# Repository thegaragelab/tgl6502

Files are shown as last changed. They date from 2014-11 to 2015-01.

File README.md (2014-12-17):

# The TGL-6502 Single Board Computer

This project implements 6502 emulator running in 4K of flash on an LPC810
microcontroller. For more information please visit [this site](http://thegaragelab.com/posts/introducing-the-tgl-6502-single-board-computer.html).

The TGL-6502

## Hardware

The hardware is very simple - the CPU itself, an SPI IO expander, two SPI memory
chips and some discrete logic. Full schematics and PCB layouts have been provided
in the *hardware* directory. The current board revision is RevB, all future work
will be using that hardware.

The hardware design is provide in [DesignSpark PCB](http://www.rs-online.com/designspark/electronics/eng/page/designspark-pcb-home-page)
format - this is a free, fully featured schematic capture and PCB layout tool
Additional formats (PDF and gerber files) have been provided in the *hardware/RevB/mfr*
directory if you prefer to use a different tool.

## Firmware

The firmware consists of a [LPCXpresso](http://www.lpcware.com/lpcxpresso) project
but is in the process of migrating to a *makefile* based build system.

## Licensing

The project is being released under the [Creative Commons Attribution-ShareAlike](http://creativecommons.org/licenses/by-sa/4.0/)
license. Some components of the project are sourced from others - their licenses
are included in their source directories.

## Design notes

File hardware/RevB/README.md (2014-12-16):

= TGL-6502 Hardware Revision B

This directory contains the design files for the RevB version of the hardware.
The core processor is still the LPC810 but the IO expander has been replaced
with a [MCP23S08](http://www.microchip.com/wwwproducts/Devices.aspx?product=MCP23S08)
8 bit expander and one of the expansion slots has been removed. The firmware will
be updated to reflect the hardware changes, the original firmware remains available
in the 'RevA' branch of the repository and any applicable changes will be merged
across as needed.

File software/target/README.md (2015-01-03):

18-Dec-2014 ShaneG

This directory contains software for the target device.

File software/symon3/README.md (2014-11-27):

This contains the source and manual for SyMON III - a system monitor for use in
6502 based systems. The original source and documentation can be found here:

        http://mypeoplepc.com/members/spacebacker/SyMon/id12.html

The source implementation uses interrupt driven IO, something the TGL-6502 does
not (yet) support.

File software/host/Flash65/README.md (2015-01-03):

18-Dec-2014 ShaneG

This utility uses a very simple protocol to transfer data to the EEPROM on the
target device.

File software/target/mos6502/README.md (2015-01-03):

18-Dec-2014 ShaneG

This directory contains 6502 specific software (mostly in assembly).

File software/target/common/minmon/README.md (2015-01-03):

20-Dec-2014 ShaneG

This contains source for a minimal monitor program (MinMon). This is designed to
make it relatively easy to manipulate memory and IO on the target device while
remaining portable. It does require a C compiler for the target.

# Memory Layout

MinMon is designed to be placed in the ROM of the target but will copy itself
to a RAM page on initialisation.

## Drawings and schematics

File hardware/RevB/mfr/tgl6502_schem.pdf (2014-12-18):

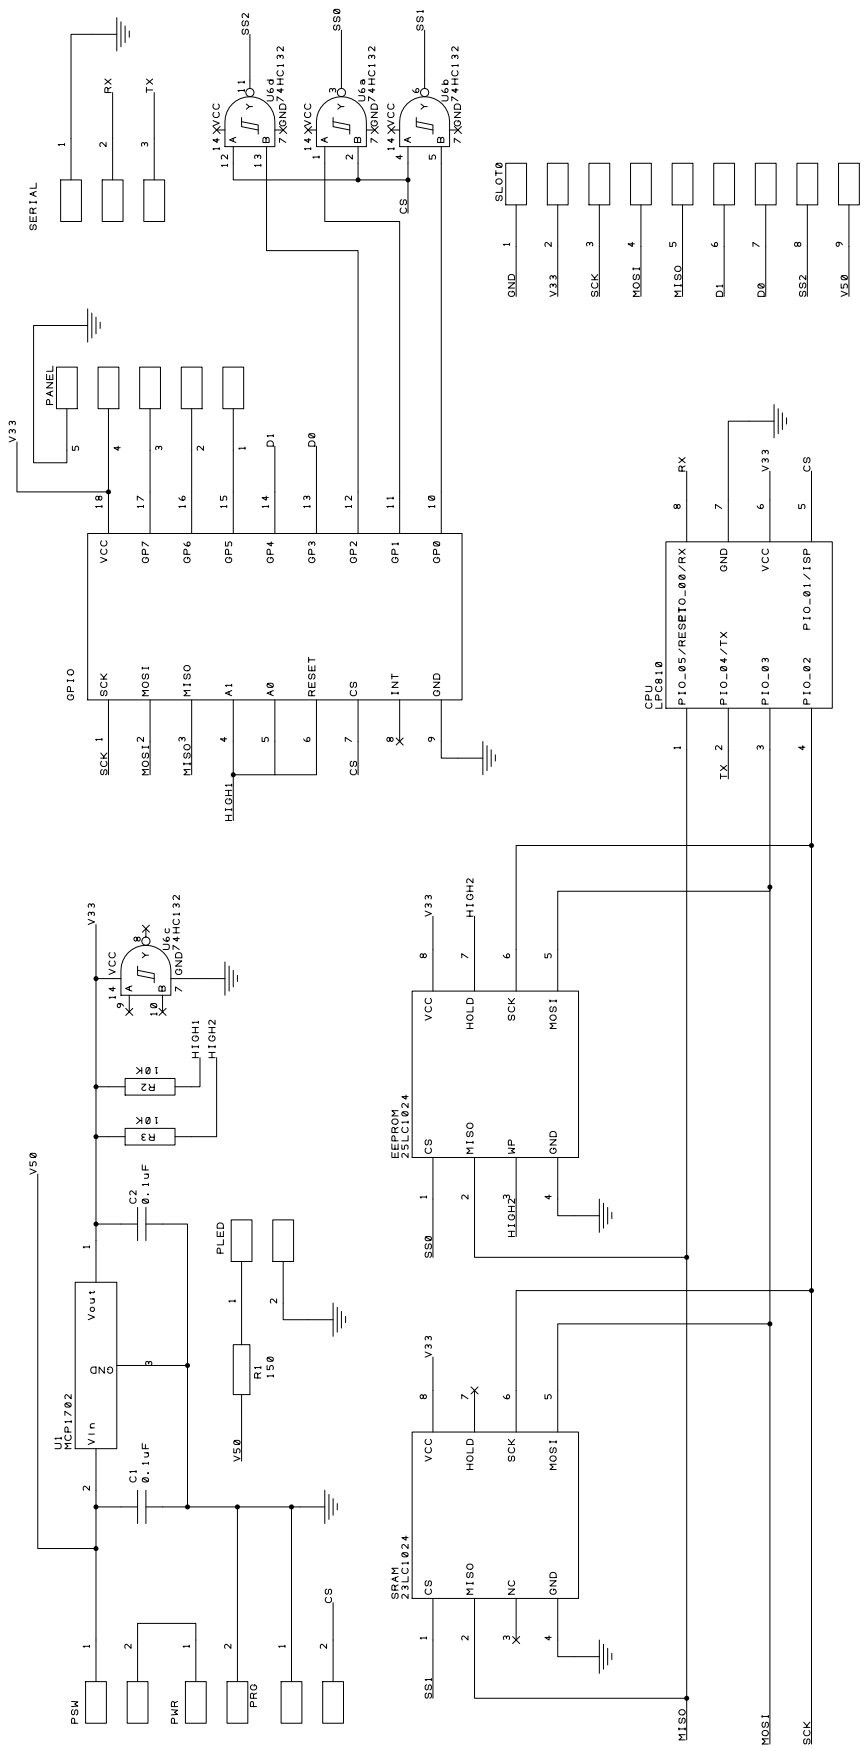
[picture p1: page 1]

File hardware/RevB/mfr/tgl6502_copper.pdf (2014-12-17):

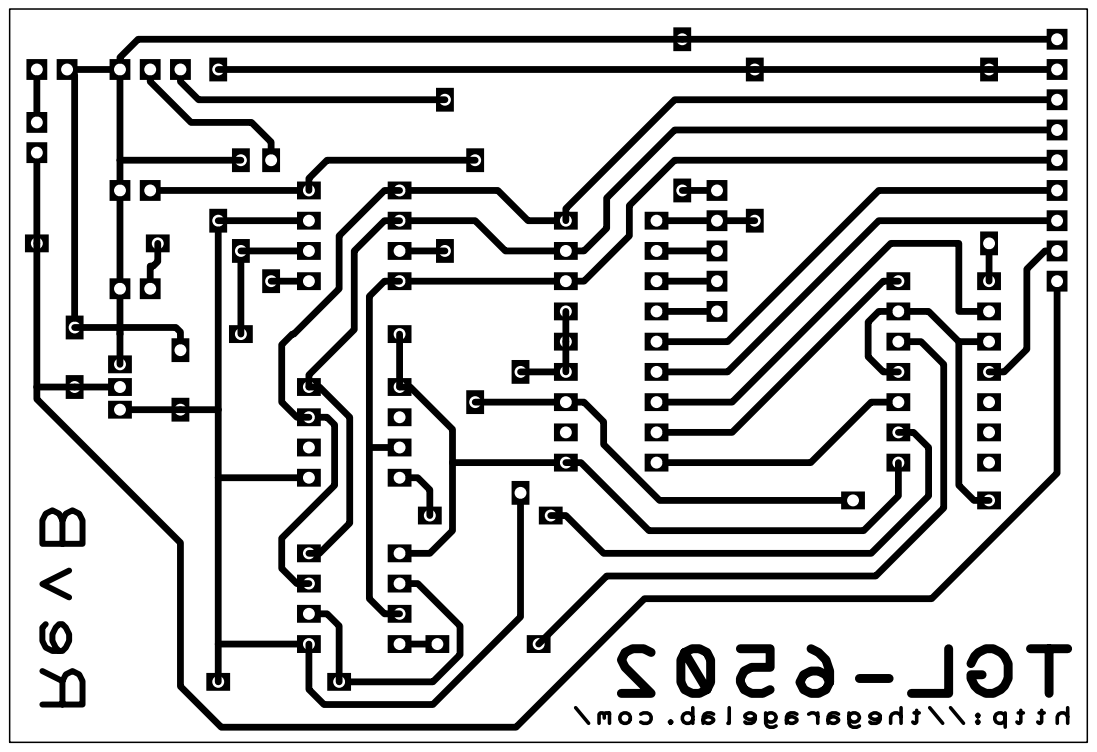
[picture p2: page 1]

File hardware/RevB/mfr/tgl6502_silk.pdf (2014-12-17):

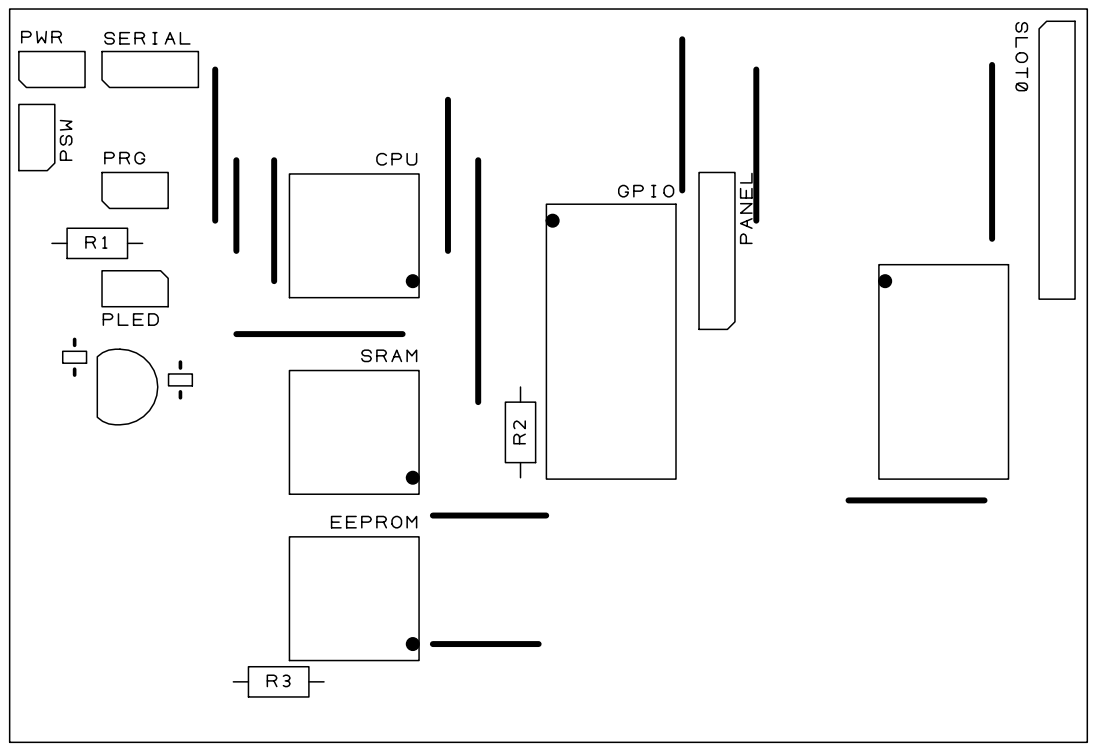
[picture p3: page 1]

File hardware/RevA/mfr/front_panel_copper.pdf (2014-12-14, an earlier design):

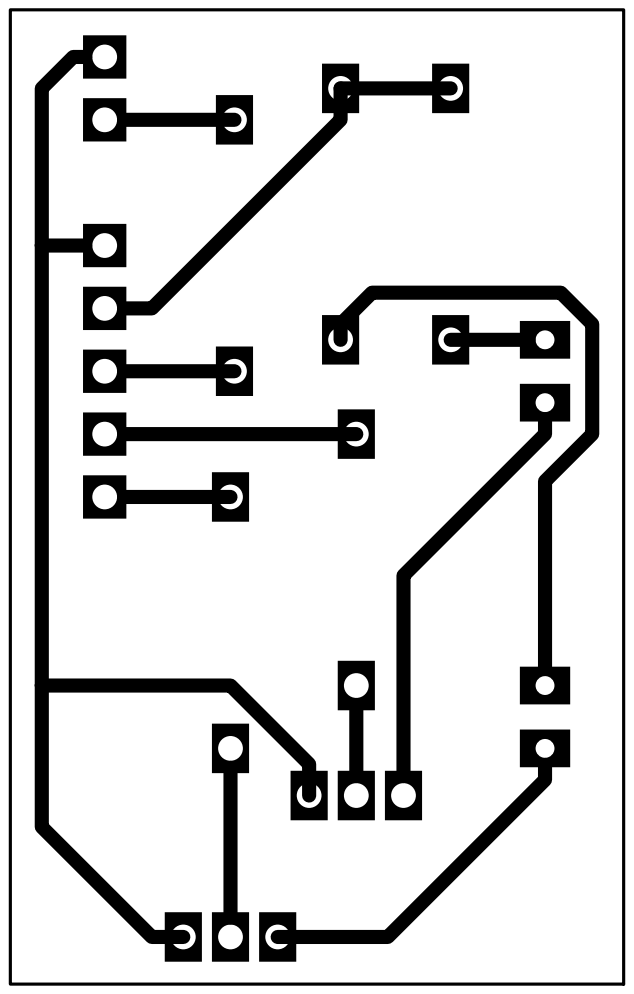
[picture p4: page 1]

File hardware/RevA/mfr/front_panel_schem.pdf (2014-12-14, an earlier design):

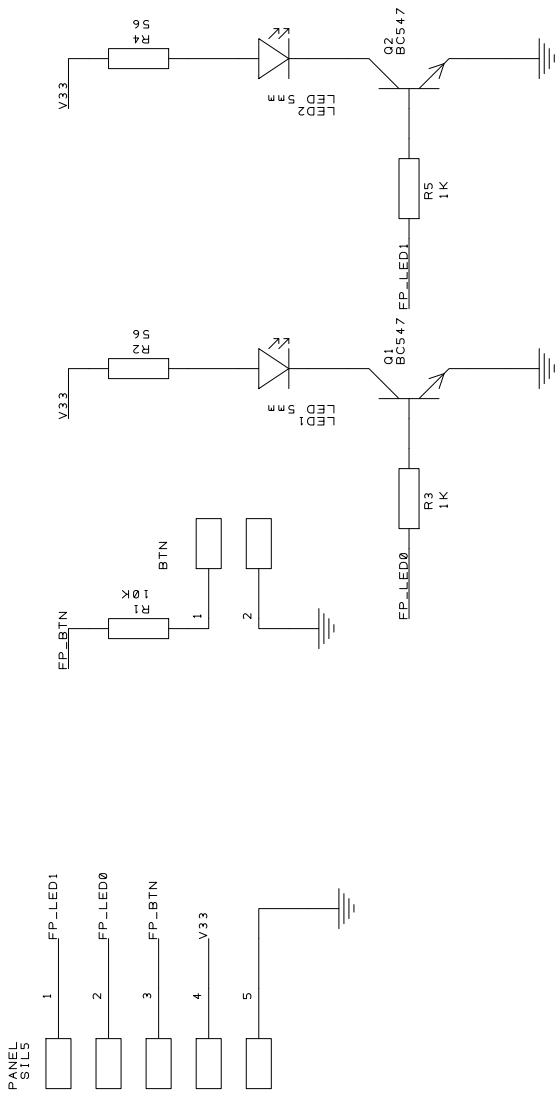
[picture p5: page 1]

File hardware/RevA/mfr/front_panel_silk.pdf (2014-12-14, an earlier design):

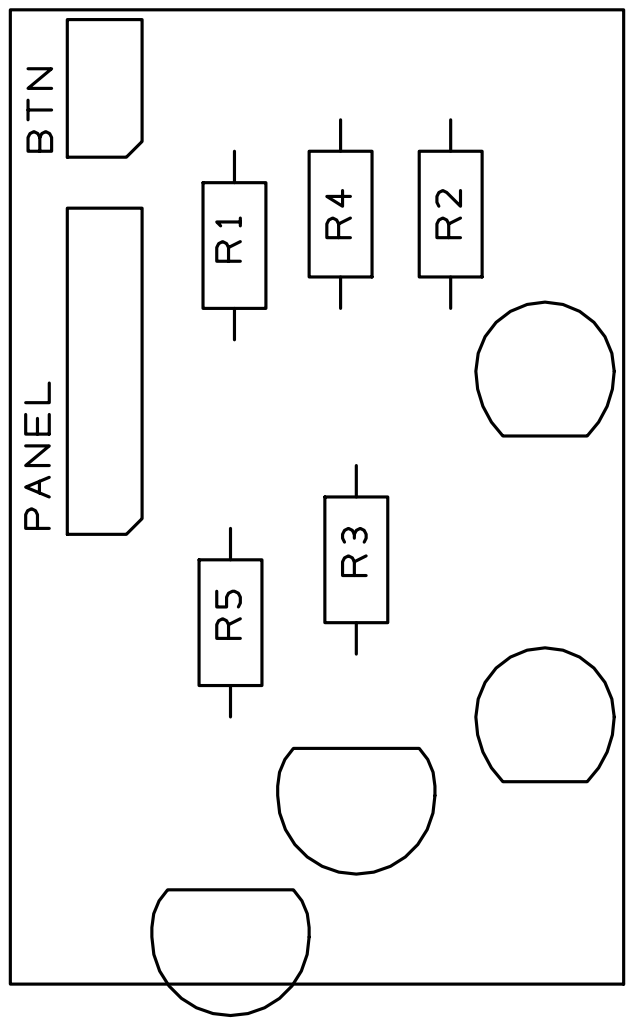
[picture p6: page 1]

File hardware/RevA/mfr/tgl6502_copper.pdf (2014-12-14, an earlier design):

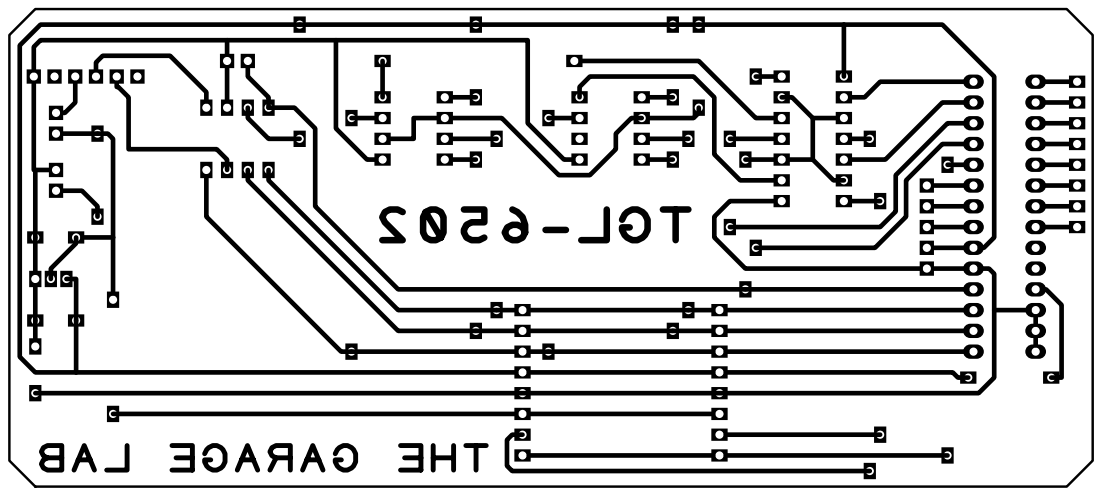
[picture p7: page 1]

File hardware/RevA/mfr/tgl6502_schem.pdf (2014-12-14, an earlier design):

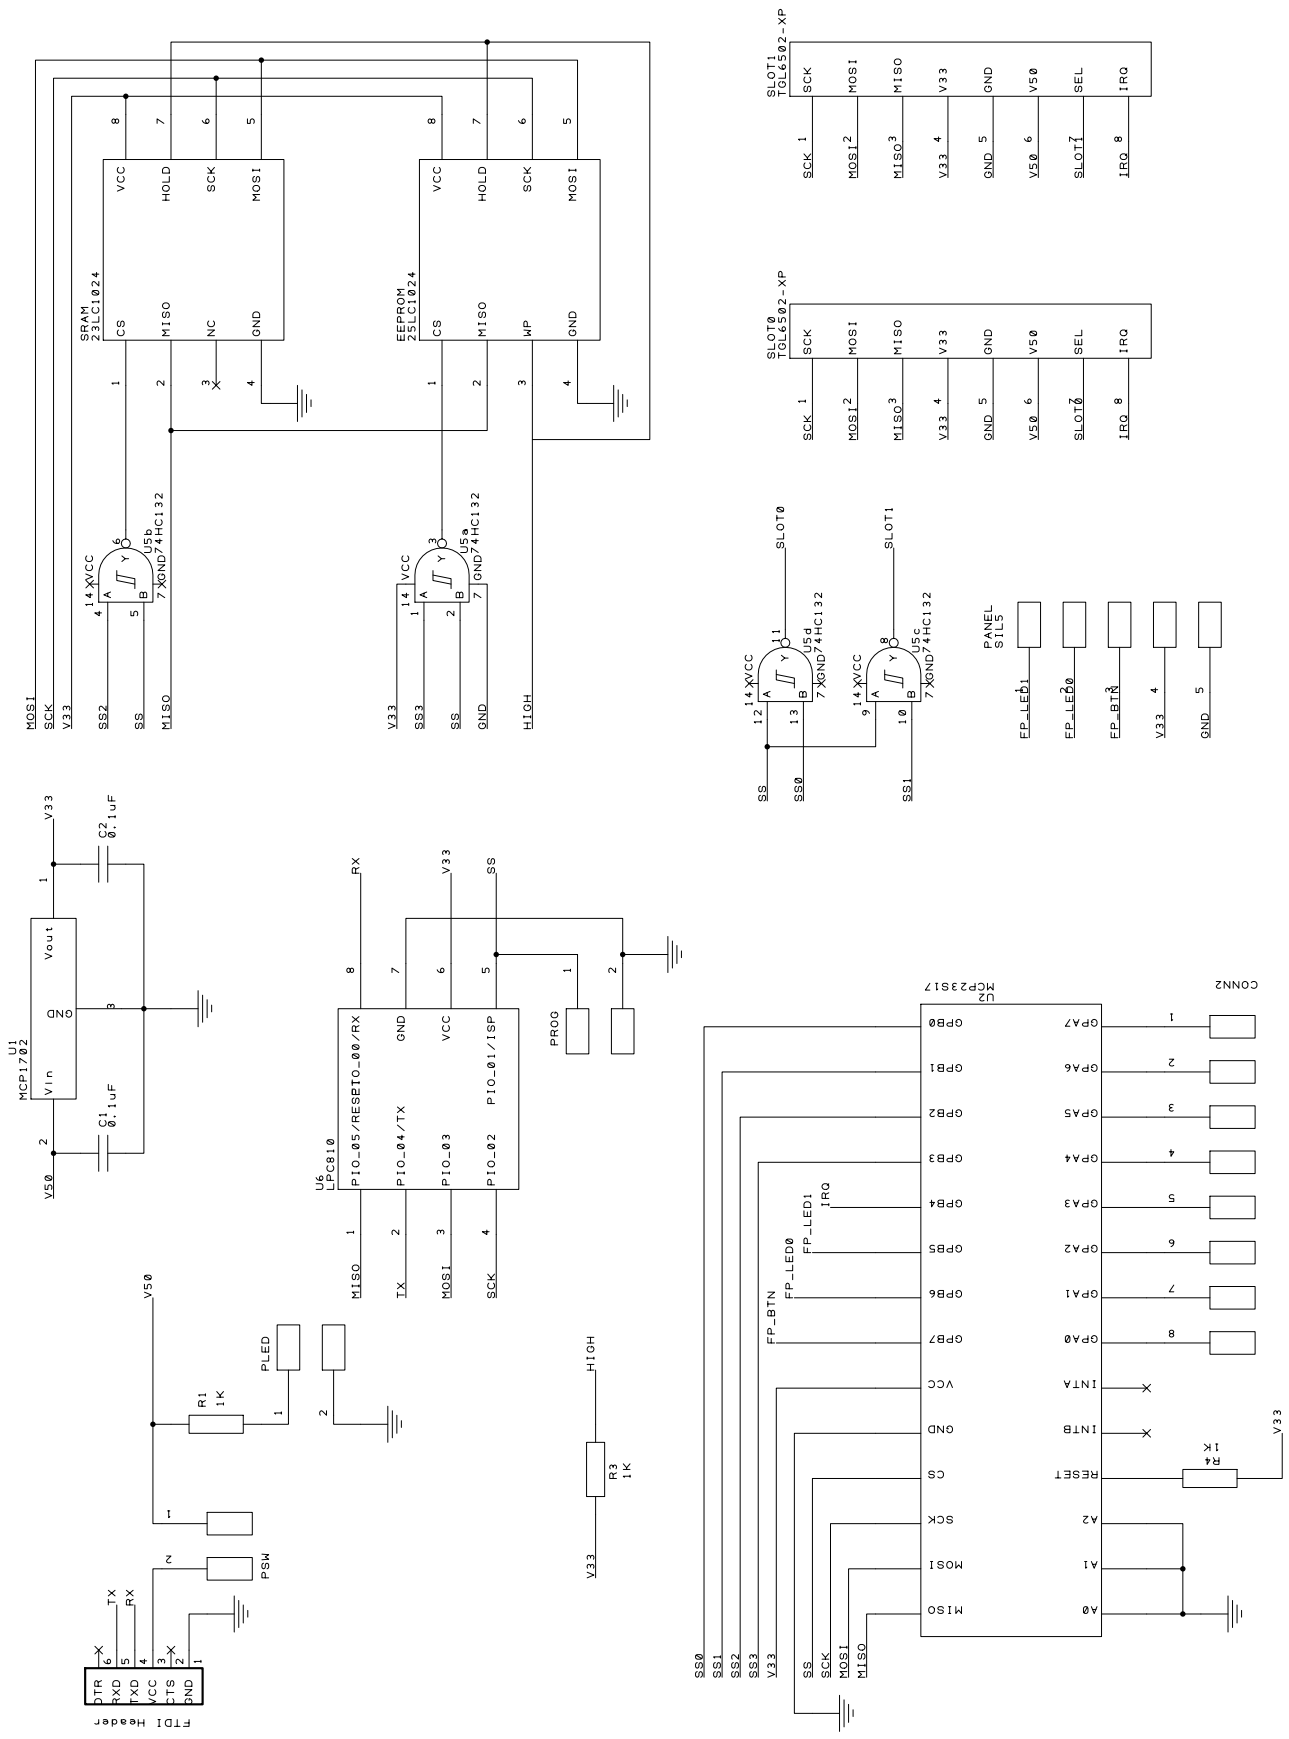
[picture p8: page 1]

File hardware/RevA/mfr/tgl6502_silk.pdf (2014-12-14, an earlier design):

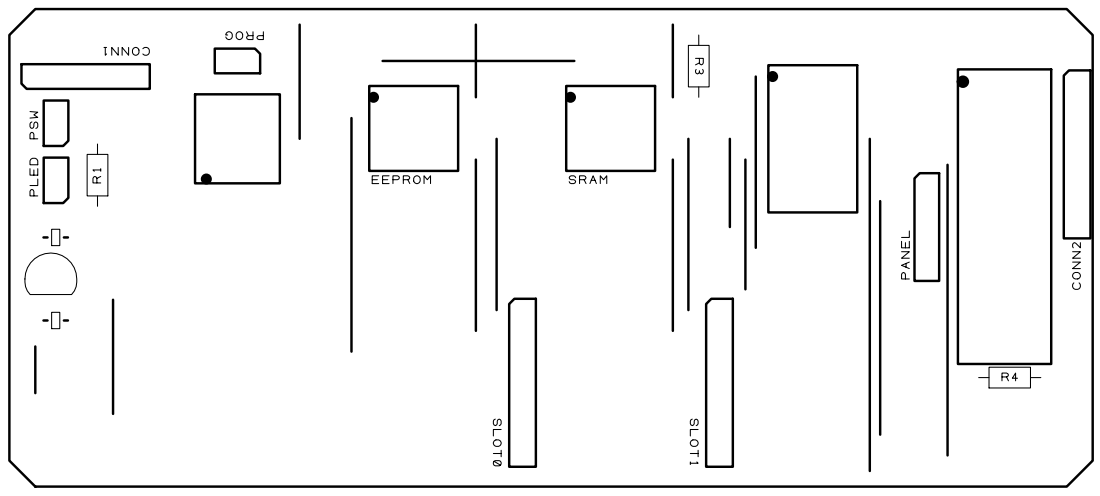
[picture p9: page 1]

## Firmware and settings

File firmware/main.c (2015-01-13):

/*--------------------------------------------------------------------------*
* 6502 CPU Emulator - Test Harness
*---------------------------------------------------------------------------*
* 24-Nov-2014 ShaneG
*
* This is a simple Windows command line application to test the emulator.
*--------------------------------------------------------------------------*/
#include <stdint.h>
#include <stdbool.h>
#include <tgl6502.h>

/** Program entry point
 */
int main(int argc, char *argv[]) {
  uint8_t ticks = 0;
  uint32_t instructions = 0;
  // Initialise the hardware
  hwInit();
  // And run the emulator
  cpuResetIO();
  cpuReset();
  while (true) {
    // Check for tick elapsed
    if(qsecElapsed()) {
      // Update instruction count
      instructions = instructions >> 6; // * 4 / 1024
      g_ioState.m_kips = (uint16_t)instructions;
      // Update time
      if(++ticks==4) {
        g_ioState.m_time++;
        ticks = 0;
        }
      // Trigger timer interrupt if needed
      if((g_ioState.m_ioctl&IOCTL_NMI_MASK)==IOCTL_NMI_TIMER)
        cpuInterrupt(INT_NMI);
      if((g_ioState.m_ioctl&IOCTL_IRQ_MASK)==IOCTL_IRQ_TIMER)
        cpuInterrupt(INT_IRQ);
      }
    // Generate interrupt on input available if set
    if(((g_ioState.m_ioctl&IOCTL_NMI_MASK)==IOCTL_NMI_INPUT)&&uartAvail())
      cpuInterrupt(INT_NMI);
    if(((g_ioState.m_ioctl&IOCTL_IRQ_MASK)==IOCTL_IRQ_INPUT)&&uartAvail())
      cpuInterrupt(INT_IRQ);
    // Execute a single instruction
    cpuStep();
    instructions++;
    }
  return 0;
  }

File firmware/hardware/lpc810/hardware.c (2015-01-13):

/*--------------------------------------------------------------------------*
* TGL-6502 Hardware Emulation
*---------------------------------------------------------------------------*
* 27-Nov-2014 ShaneG
*
* This provides the hardware interface to the SPI peripheral and provides
* the emulator access to them.
*--------------------------------------------------------------------------*/
#include <stdio.h>
#include <stdint.h>
#include <stdbool.h>
#include <tgl6502.h>
#include "LPC8xx.h"

//! Size of memory (both RAM and ROM)
#define MEMORY_SIZE (128 * 1024)

//! IO state information
IO_STATE g_ioState;

//---------------------------------------------------------------------------
// Version information
//
// The version byte indicates the hardware platform in the upper nybble and
// the firmware version in the lower. Available platforms are:
//
//  0 - The desktop simulator.
//  1 - LPC810 based RevA hardware
//  2 - LPC810 based RevB hardware
//---------------------------------------------------------------------------

// This files supports RevA and RevB boards so the HW version may be defined
// as part of the build process. If not assume a RevA board.
#if !defined(HW_VERSION)
#  define HW_VERSION 1
#endif
#define FW_VERSION 1

// The single version byte (readable from the IO block)
#define VERSION_BYTE ((HW_VERSION << 4) | FW_VERSION)

//----------------------------------------------------------------------------
// Hardware setup
//----------------------------------------------------------------------------

//! System ticks timer
static volatile uint32_t s_timeNow = 0;

/** Implement the system tick interrupt
 *
 */
void SysTick_Handler(void) {
  s_timeNow++;
  }

/** Determine if a quarter second has elapsed.
 *
 * @return true if 0.25 seconds has passed.
 */
bool qsecElapsed() {
  if(s_timeNow>=250) {
    s_timeNow = 0;
    return true;
    }
  return false;
  }

//---------------------------------------------------------------------------
// Core UART access
//---------------------------------------------------------------------------

//! Baud rate to use for communication
#define BAUD_RATE 57600

//! UART control flags
#define UART_ENABLE          (1 << 0)
#define UART_DATA_LENGTH_8   (1 << 2)
#define UART_PARITY_NONE     (0 << 4)
#define UART_STOP_BIT_1      (0 << 6)

//! UART Status bits
#define UART_STATUS_RXRDY    (1 << 0)
#define UART_STATUS_RXIDLE   (1 << 1)
#define UART_STATUS_TXRDY    (1 << 2)
#define UART_STATUS_TXIDLE   (1 << 3)
#define UART_STATUS_CTSDEL   (1 << 5)
#define UART_STATUS_RXBRKDEL (1 << 11)

/** Send a single character over the UART
 *
 * This is a blocking operation. If the transmitter is not yet ready the
 * function will block until it can send the character.
 *
 * @param ch the character to send.
 */
void uartWrite(uint8_t ch) {
  /* Wait until we're ready to send */
  while (!(LPC_USART0->STAT & UART_STATUS_TXRDY));
  LPC_USART0->TXDATA = ch;
  }

/** Read a single character from the UART
 *
 * This is a blocking operation. If no data is available the function will
 * block until it is. Use the 'uartRead()' function to determine if data is
 * available.
 *
 * @return the character read from the UART
 */
uint8_t uartRead() {
  /* Wait until we're ready to receive */
  while (!(LPC_USART0->STAT & UART_STATUS_RXRDY));
  return LPC_USART0->RXDATA;
  }

/** Determine if data is available to read
 *
 * @return true if data is available and a call to 'uartRead()' would return
 *              immediately.
 */
bool uartAvail() {
  return (LPC_USART0->STAT & UART_STATUS_RXRDY);
  }

//---------------------------------------------------------------------------
// Core SPI access
//---------------------------------------------------------------------------

//--- Master select pin
#define MASTER_SELECT           1

//--- SPI configuration flags
#define SPI_CFG_ENABLE          (1 << 0)
#define SPI_CFG_MASTER          (1 << 2)
#define SPI_CFG_CPHA            (1 << 4)

//--- SPI transfer flags
#define SPI_TXDATCTL_EOT        (1 << 20)
#define SPI_TXDATCTL_FSIZE(s)   ((s) << 24)
#define SPI_STAT_RXRDY          (1 << 0)
#define SPI_STAT_TXRDY          (1 << 1)

//! Enable the master (IO expander) SPI device
#define masterEnable()  LPC_GPIO_PORT->B0[1] = 0

//! Disable the master (IO expander) SPI device
#define masterDisable() LPC_GPIO_PORT->B0[1] = 1

/** Transfer a single data byte via SPI
 *
 * @param data the 8 bit value to send
 *
 * @return the data received in the transfer
 */
uint8_t spiTransfer(uint8_t data) {
  while ( (LPC_SPI0->STAT & SPI_STAT_TXRDY) == 0 );
  LPC_SPI0->TXDATCTL = SPI_TXDATCTL_FSIZE(8-1) | SPI_TXDATCTL_EOT | data;
  while ( (LPC_SPI0->STAT & SPI_STAT_RXRDY) == 0 );
  return LPC_SPI0->RXDAT;
  }

//---------------------------------------------------------------------------
// Peripheral access helpers
//---------------------------------------------------------------------------
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

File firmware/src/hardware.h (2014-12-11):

/*--------------------------------------------------------------------------*
* TGL-6502 Hardware Emulation
*---------------------------------------------------------------------------*
* 27-Nov-2014 ShaneG
*
* This provides the hardware interface to the SPI peripheral and provides
* the emulator access to them.
*--------------------------------------------------------------------------*/
#ifndef __HARDWARE_H
#define __HARDWARE_H

#ifdef __cplusplus
extern "C" {
#endif

//! Size of memory (using same size for ROM and RAM)
#define MEMORY_SIZE (128 * 1024)

//! The start of ROM space in physical memory
#define ROM_BASE 0x00080000L

//! The start of IO space in CPU memory
#define IO_BASE 0xFF00

//! Size of EEPROM page (TODO: Can be up to 256, the larger the better)
#define EEPROM_PAGE_SIZE 128

//! Millisecond system timer
extern uint32_t g_millis;

#pragma pack(push, 1)

/** Represents the memory mapped IO area
 *
 * This structure maintains data for the memory mapped IO area.
 */
typedef struct _IO_STATE {
  uint16_t    m_time;                    //!< RW: Current time (seconds since midnight)
  uint16_t    m_kips;                    //!< RO: Instructions per second (1000s)
  uint8_t     m_ioctl;                   //!< RW: IO control flags
  uint8_t     m_conin;                   //!< RO: Console input
  uint8_t     m_conout;                  //!< RW: Console output
  uint8_t     m_slot0;                   //!< RW: Expansion slot control
  uint8_t     m_spicmd;                  //!< RW: SPI control byte
  uint8_t     m_spibuf[SPI_BUFFER_SIZE]; //!< RW: SPI transfer buffer
  uint8_t     m_pages[MMU_PAGE_COUNT];   //!< RW: MMU page map
  } IO_STATE;

#pragma pack(pop)

/** IO Offsets
 *
 * Offset into the IO area for each entry. This *MUST* match the IO_STATE
 * structure.
 */
typedef enum {
  IO_OFFSET_TIME  = 0,
  IO_OFFSET_KIPS  = 2,
  IO_OFFSET_IOCTL = 4,
  IO_OFFSET_CONIN = 5,
  IO_OFFSET_CONOUT = 6,
  IO_OFFSET_SLOT0 = 7,
  IO_OFFSET_SPICMD = 8,
  IO_OFFSET_SPIBUFF = 9,
  IO_OFFSET_PAGES = 9 + SPI_BUFFER_SIZE,
  } IO_OFFSET;

/** IO control bits and masks
 */
typedef enum {
  IOCTL_LED0      = 0x01, //!< Control LED0 state
  IOCTL_LED1      = 0x02, //!< Control LED1 state
  IOCTL_CONDATA   = 0x04, //!< Data is available to read from the console
  IOCTL_BUTTON    = 0x08, //!< Front panel button state
  //--- IRQ source
  IOCTL_IRQ_MASK  = 0x30, //!< Mask for IRQ source control
  IOCTL_IRQ_NONE  = 0x00, //!< IRQ disabled
  IOCTL_IRQ_TIMER = 0x10, //!< IRQ triggered by timer
  IOCTL_IRQ_INPUT = 0x20, //!< IRQ triggered by console input
  IOCTL_IRQ_SLOT  = 0x30, //!< IRQ triggered by slot D0
  //--- NMI source
  IOCTL_NMI_MASK  = 0xC0, //!< Mask for NMI source control
  IOCTL_NMI_NONE  = 0x00, //!< NMI disabled
  IOCTL_NMI_TIMER = 0x40, //!< NMI triggered by timer
  IOCTL_NMI_INPUT = 0x80, //!< NMI triggered by console input
  IOCTL_NMI_SLOT  = 0xC0, //!< NMI triggered by slot D0
  } IOCTL_FLAGS;

/** Slot 0 control bits and masks
 */
typedef enum {
  SLOT_D0_VAL = 0x01, //!< Value of pin D0
  SLOT_D1_VAL = 0x02, //!< Value of pin D1
  SLOT_D0_DIR = 0x04, //!< Direction of pin D0
  SLOT_D1_DIR = 0x08, //!< Direction of pin D1
  } SLOT_FLAGS;

//! The global IO state information
extern IO_STATE g_ioState;

/** Initialise the UART interface
 *
 * Configures the UART for 57600 baud, 8N1.
 */
void uartInit();

/** Send a single character over the UART
 *
 * This is a blocking operation. If the transmitter is not yet ready the
 * function will block until it can send the character.
 *
 * @param ch the character to send.
 */
void uartWrite(uint8_t ch);

/** Send a sequence of bytes to the UART
 *
 * Sends the contents of a NUL terminated string over the UART interface.
 */
void uartWriteString(const char *cszString);

/** Read a single character from the UART
 *
 * This is a blocking operation. If no data is available the function will
 * block until it is. Use the 'uartRead()' function to determine if data is
 * available.
 *
 * @return the character read from the UART
 */
uint8_t uartRead();

/** Determine if data is available to read
 *
 * @return true if data is available and a call to 'uartRead()' would return
 *              immediately.
 */
bool uartAvail();

/** Initialise SPI interface
 *
 * Set up SPI0 as master in mode 0 (CPHA and CPOL = 0) at 10MHz with no delays.
 * SSEL is not assigned to an output pin, it must be controlled separately.
 */
void spiInit();

/** Transfer a single data byte via SPI
 *
 * @param data the 8 bit value to send
 *
 * @return the data received in the transfer
 */
uint8_t spiTransfer(uint8_t data);

/** Initialise the external hardware
 *
 * This function needs to be called after the SPI bus has been initialised and
 * the pin switch matrix has been set up. It will initialise the external SPI
 * components.
 */
void hwInit();
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

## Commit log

2014-11-23 Added initial hardware.
    [tgl65.sch]
2014-11-25 Added a sample EhBASIC program to calculate the first 100 prime numbers. Using this to generate memory hit/miss statistics.
2014-11-25 Started adding some documentation. This is an analysis of the cost of using paragraph based caching versus direct read/write on a per byte basis.
    [paragraph_analysis.xlsx]
2014-11-25 Integrated into the LPC810 project. Unfortunately it is way too large (6198 bytes for the emulator core itself).
    [main.c]
2014-11-26 Refactored. Removed two large tables of function pointers and replaced them with two large switch statements.
2014-11-26 Changed to small (1 byte per entry) tables instead of large switch statements. Now down to 3168 bytes.
2014-11-26 Removed printf implementation, it's not required.
2014-11-26 An older version of the hardware design. Added for safe keeping.
    [my65.sch]
2014-11-27 Fleshing out LPC810 hardware interface and refactoring to support this. Current firmware size is 3780 bytes.
2014-11-27 Updates to the Visual Studio project. Will not build at this stage - will need to work on that later.
2014-11-27 Moved samples into their own directory.
2014-11-29 Removed previous versions of the hardware.
    [my65.sch, tgl65.sch]
2014-11-29 Added the LPC810 version of the hardware and the common front panel (LED/Button).
    [front_panel.sch, tgl6502.sch]
2014-12-07 Adding files for CNC cutting of the case.
2014-12-07 Updating PCB layout
2014-12-07 Joined side and bottom parts of case into a single file. Added a g-code file for cutting the case.
2014-12-07 Updated cutting depth and safe height for the case frame.
2014-12-10 Updated paragraph analysis with corrected cost figures.
    [paragraph_analysis.xlsx]
2014-12-10 Fixed typos in last commit, added IO pin definitions.
    [hardware.c, hardware.h]
2014-12-10 Left over from merge.
    [paragraph_analysis.xlsx]
2014-12-10 Fixed register access for driving GPIO port.
    [hardware.c]
2014-12-11 Started work on a tool to load the EEPROM contents to the board.
2014-12-13 Using stringizing operator to convert firmware version into banner string. Added delay at start up prior to UART operations to avoid line noise.
    [main.c]
2014-12-14 Fixed endless loop bug in eeprom loader mode and now sending checksum back on reads (forgot about that before).
    [main.c]
2014-12-14 Fixed incorrect phase on SPI.
    [hardware.c]
2014-12-14 Refactoring hardware directory layout to make room for future revisions.
    [front_panel.sch, tgl6502.sch]
2014-12-14 Updated DesignSpark PCB schematics.
    [front_panel.sch, tgl6502.sch]
2014-12-14 Added manufacturing data (gerbers, PDF, etc).
    [front_panel.gbl, tgl6502.gbl]
2014-12-15 Added HW/FW version information (make it available to the emulator core as well). Removed last traces of EEPROM writing and made size of simulated memory a hardware implementation decision.
2014-12-16 Added RevB design. Need to review again before building it.
    [tgl6502.sch]
2014-12-17 Added manufacturing files for RevB board. Note - these are not yet tested.
    [tgl6502.gbl]
2014-12-18 Updated component values.
    [tgl6502.sch]
2014-12-18 Updated Makefile - now works on Windows with cygwin and the Windows package for arm-none-eabi-gcc
2014-12-19 Fixed makefile for linux builds, replaced <conio.h> calls with <termios.h> functions when compiling under linux.
    [hardware.c, main.c]
2014-12-19 Removed 'uartWriteString()' function - never used by the emulator.
2014-12-21 Renamed configuration file - initial cut had the file extension wrong.
2014-12-22 Added support for interrupt vectors.
2014-12-22 Add basic support for hardware (simple non-interrupt console access).
2015-01-06 Automatically add assembler files to the list of things to be compiled.
2015-01-06 Updated for the MCP23S08 chip and new board layout.
2015-01-06 There is only 1 slot.
2015-01-13 Adding timer and interrupt code. Have overfilled the flash again on the LPC810.
2015-01-13 We know all the settings in advance so avoid referencing registers in calculating auxillary values - this stops the division helper functions being brought in (saves 200+ bytes).
    [hardware.c]
2015-01-13 Added input available interrupt support.
2015-01-14 Fixed serious memory decoding bug in the local emulator.
    (cherry picked from commit 7e588616be52f42d118730f6d32f64bac8039a43)
    [hardware.c]
